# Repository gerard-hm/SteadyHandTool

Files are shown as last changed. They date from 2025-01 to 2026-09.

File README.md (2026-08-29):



# Steady Hand Tool

> “When you're racing against your own biology, the **story** is just the exhaust; the **science is the engine** and time is the fuel.”

<p align="center">
  Steady Hand Tool v1
  <br>
</p>
<p align="center">
  Steady Hand Tool v1
  <br>
</p>
<p align="center">
  Steady Hand Tool v1
  <br><br><br>
  <em>Steady Hand Tool: Mechanical stability for a wandering hand.</em>
</p>

## See it in Action
<p align="center">
  <a href="https://www.youtube.com/watch?v=Imng8o2QRBg">
    Steady Hand Tool Video
  </a>
  <br>
  <em>Demonstrating the stability and precision of the Steady Hand Tool.</em>
</p>

---

Steady Hand Tool is a manual SMD (Surface Mount Device) assembly stabilizer designed to help makers and professionals prototype PCBs with high precision. Originally created to overcome physical challenges—specifically hand tremors caused by Parkinson’s disease—this tool makes high-accuracy soldering accessible to everyone.

## 🌟 Key Features

* **Stabilized 4-DOF Movement:** Keeps your hand on a steady track while allowing full vertical and horizontal reach.
* **Near-Zero Friction:** Equipped with **14 high-quality metal bearings** and carbon fiber rods for smooth, silent, and effortless operation.
* **Modular Magnetic Coupler:** Features a quick-swap magnetic system for changing tool heads (tweezers, vacuum tips, etc.) in seconds.
* **Purely Mechanical:** No power required, no cables, and no noise. It's always ready to work when you are.
* **Heavy-Duty Base:** A weighted **680g (1.5 lb)** base ensures the arm remains stable even at full extension.
* **Open Source:** Designed to be hacked and customized. Create your own tool heads to suit your specific workflow.

## 🚀 Get Yours

<p align="center">
  <a href="https://www.crowdsupply.com/halfmarble/steady-hand-tool">
    
  </a>
</p>

<p align="center">
  <b>The Steady Hand Tool is coming to <a href="https://www.crowdsupply.com/halfmarble/steady-hand-tool">Crowd Supply</a>.</b><br>
  Sign up to be notified when the campaign launches.
</p>

---

## 🛠 Technical Specifications

* **Reach:** Approximately 250 mm (9.8 in) vertical and horizontal travel.
* **Construction:** 3D-printed components (optimized for PETG/Carbon Fiber) and 8mm carbon fiber rods.
* **Bearings:** MR128ZZ precision shielded bearings.
* **Compatibility:** Designed to support a pair of specialized reverse tweezers optimized for 0805-size components and smaller.

> [!TIP]
> **Looking to build it?** Check out our [Assembly Guide](https://github.com/gerard-hm/SteadyHandTool/blob/main/docs/assembly-guide.md) for step-by-step instructions.

## 📂 Repository Structure

```
steady-hand-tool/
├── .github/                # Issue templates and GitHub-specific config
├── hardware/               # All physical design files
│   ├── models/             # 3D models for printing
│   │   ├── stl/            # Ready-to-print files (standard)
│   │   │   ├── 3rdParty/   # Adapters for 3rd party tools
│   │   ├── step/           # High-fidelity files for CAD software
│   │   └── community/      # User-submitted tool heads
│   ├── electronics/        # (Optional) If you ever add sensors/LEDs
│   └── reference/          # Technical drawings or dimension sheets
├── docs/                   # Documentation and guides
│   ├── assembly-guide.md   # Step-by-step build instructions
│   ├── images/             # Photos and GIFs used in the guides
│   └── calibration.md      # How to tune the arm for smooth movement
├── media/                  # Marketing photos and build images
├── .gitignore              # Tells Git which files to ignore (like temp CAD files)
├── BOM.md                  # Bill of Materials (the "Shopping List")
├── CONTRIBUTING.md         # How others can help
├── LICENSE                 # CERN-OHL-S-2.0 License text
└── README.md               # The front page of your project
```

---

## ⚙️ Our Mission

"It's the only tool that I have, to help me and others manage our own **slice of PD hell.**"

The Steady Hand Tool is an engineering response to a personal biological war. It exists because "making" is a vital part of staying human. Inspired by the lived reality of Parkinson’s Disease, this tool is engineered to ensure that biological constraints never dictate the boundaries of human creativity.

## 🔧 Our Support

This is a race against time and biology. We invite you to pick up a wrench and help us optimize the hardware for the next generation of makers facing similar constraints. Feedback, CAD iterations, and mechanical refinements are the high-octane fuel that keeps this engine running.

<p align="left">
  <b>10% of the net profit</b> from selling the Steady Hand Tool will go directly to support
  <a href="https://give.michaeljfox.org/halfmarble">Team Fox</a>, the grassroots fundraising program of
  The Michael J. Fox Foundation for Parkinson’s Research.
  <br>
  <em>halfmarble is an independent Team Fox third-party fundraiser.</em>
</p>

---

## License

This project is licensed under the [**CERN-OHL-S-2.0 License**](https://choosealicense.com/licenses/cern-ohl-s-2.0/) - see the [LICENSE](LICENSE) file for details.

## Trademarks

The license above covers this repository’s hardware designs and documentation. It grants no rights to any trademark, trade name, or logo — including the Team Fox and Michael J. Fox Foundation marks, and halfmarble’s own.

---

## Credits

**Photography:** Hero images provided by [Crowd Supply](https://www.crowdsupply.com).

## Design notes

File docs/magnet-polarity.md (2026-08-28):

# Magnet Polarity Standard

Magnet orientation is the one part of this design that **cannot be recovered from a model
file**. An STL describes a ⌀4 mm hole; it says nothing about which way the magnet in that hole
faces. Two people can print the same adapter from the same file, populate it correctly by every
visible measure, and end up with parts that push each other away.

This document fixes that, so an adapter designed by one person clicks into a base owned by
another.

## The rule

> **Fixed parts present NORTH. Removable parts present SOUTH.**

| Part | Role | Exposed pole |
| :--- | :--- | :--- |
| Base tool pockets | fixed | **North** |
| Carriage tool interface | fixed | **North** |
| Tool adapters | removable | **South** |

**Every magnet in a single array shares the same pole.** There is no alternating pattern and no
keyed position. Any rotation seats correctly.

## Geometry

Each of the four base pockets holds six ⌀4 × 2 mm neodymium magnets on a **⌀18 mm bolt circle,
60° apart**. Seats are 2 mm deep, so a correctly seated magnet sits flush with the pocket floor.

```
        pocket, viewed from above          side view, one seat

              N     N                      ___________________
           N           N                   |    magnet   |     <- N face up, flush
              N     N                      |_____________|
                                           |   ⌀1.5 air relief
        all six the same pole              |
        ⌀18 bolt circle, 60 deg apart      v  ballast chamber
```

The ⌀1.5 mm hole under each seat is air relief — it lets a magnet press home instead of riding
on trapped air. It is not a through-hole to the outside.

## Installing without a compass

Neodymium magnets ship as a stack, uniformly polarised. **Do not separate the stack and sort the
magnets.** Slide one magnet off the end of the stack at a time and drop it straight into its
seat without turning it over. Every magnet then lands the same way round, and you only have to
verify the array once rather than six times.

If a magnet flips itself as it approaches the seat, it was already attracted to a neighbour in
the wrong orientation — take it out and start that seat again.

## Verifying the array

**Against known-good hardware, which is the easy case.** Offer a factory-built adapter to the
array. If it snaps flat and stays put at every rotation, the array is correct. If it pushes away
or sits proud on one side, the array is inverted.

**With a compass, for a first build.** A compass needle's marked, north-seeking end is a magnetic
*north* pole, so it is attracted to a magnet's *south* pole. Hold the compass over a seated
magnet in a base pocket:

- The marked end is **pushed away** — correct, the seat presents north.
- The marked end is **pulled in** — inverted, that array presents south.

Check one magnet per array. Because the stack method makes all six identical, one check settles
the pocket.

## If you get it wrong

A fully inverted array is harmless and reversible — the adapter simply will not stick, and the
magnets press out from the relief hole with a pin. A *single* reversed magnet among five correct
ones is the case worth avoiding: the part still holds, but it rocks on the odd magnet and the
holding force drops noticeably. That is why the whole array shares one pole. There is no phase to
get right, and a mistake is obvious rather than subtle.

## Hardware built before this standard

This document fixes the convention going forward. Prototypes assembled before it exists may be
polarised either way, because nothing recorded which way they went — that is the whole reason for
writing it down.

**Build production hardware to the standard above, not to a prototype.** If an old base and a new
adapter push apart, the old base predates the convention; it is not evidence that the convention
is wrong.

Re-polarising an existing part is straightforward and reversible. Push each magnet out through
its ⌀1.5 mm air-relief hole with a pin, turn it over, and press it back in. There is no adhesive
and nothing to damage.

## For adapter designers

Build to **south exposed** and your adapter will seat in any base built to this standard, at any
rotation. Copy the seat pattern from `InterfaceTemplate.stl` rather than re-deriving it — the
⌀18 bolt circle and 2 mm seat depth are what make the parts interchangeable, and the polarity
rule above is what makes them interchangeable *between owners*.

## Why not alternating poles

Alternating north and south around the ring would hold harder, because flux closes between
neighbours, and it would key the adapter to three rotational positions. It was rejected: a
mis-phased adapter would actively *repel* its base, which is a poor failure mode for someone
seating a tool one-handed with a tremor. Uniform polarity trades some holding force for an
interface that cannot be assembled out of phase.

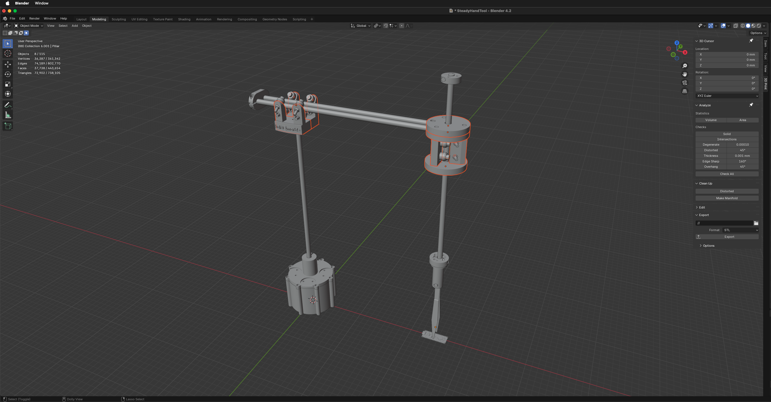
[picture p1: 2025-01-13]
SteadyHandToolModel.png

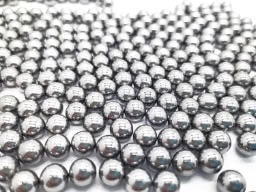
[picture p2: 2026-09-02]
media/weights.jpg

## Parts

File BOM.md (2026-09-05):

# Steady Hand Tool

**A stabilizing pick-and-place arm for precision SMD assembly.**




<p align="center">
  Steady Hand Tool v1
  <br>
  <em>Steady Hand Tool — when you need help holding down really tiny parts.</em>
</p>

---

## 🛒 Bill of Materials (BOM)

The Steady Hand Tool is designed for easy sourcing. You can find the links and visual references for each component below (please notice that these are affiliate links).

### 🏗️ Structural Hardware

| Image | Item | Specification | Purpose |
| :---: | :--- | :--- | :--- |
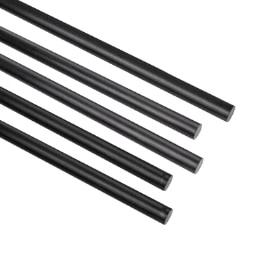
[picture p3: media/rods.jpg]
|  | [**Carbon Fiber Rods**](https://amzn.to/4jpyyZC) | 8mm Diameter x 300mm (**4 required**) | 2 horizontal rails, 1 vertical mast, 1 vertical tool rod |
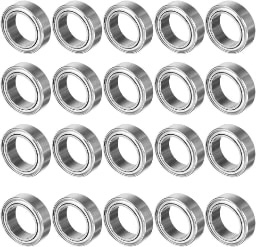
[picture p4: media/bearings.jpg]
|  | [**MR128ZZ Bearings**](https://amzn.to/42kMWMD) | 8x12x3.5mm (14 required) | Frictionless carriage movement |
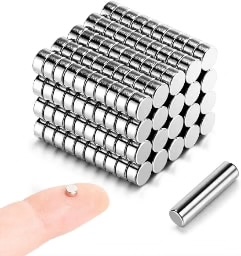
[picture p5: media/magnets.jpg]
|  | [**Magnets**](https://amzn.to/4hq1puZ) | 4mm x 2mm Neodymium (56 required, buy 60) | Magnetic tool coupler interface. **Orientation matters** — see the [Magnet Polarity Standard](docs/magnet-polarity.md) |
| | **Base Ballast** | Round steel shot, **1.5 - 2.0 mm** (nominal 2.0 mm). Approx. **517 g** per base | Fills the printed base to **680 g ± 10 g**. The machined aluminium base needs none. **Size is not a preference** — read the note below before you buy any |

**Magnet count, broken down:** 24 in the base (four tool pockets, six each), 24 in the four
tool adapters, and 8 in the tool interface — 56 in total. Buy 60; they are small, and one
will find the floor.

**On the ballast, before you buy any.** The shot goes into the printed base through a **⌀8 mm
socket**, and that socket — not the chamber — is what governs. Granular flow arches when the
opening falls below roughly four particle diameters, so anything much over 2 mm bridges at the
mouth and leaves the outer chamber empty. At the other end, the chamber vents are ⌀1.5 mm and
finer shot runs straight back out. **So: 1.5 - 2.0 mm, nominal 2.0.** SAE **S-780** blasting shot
and **#9 steel reloading shot** both sit in that window.

**This entry used to link to 6.35 mm slingshot ammo, and it does not work.** A base filled with it
reaches about **619 g against the 680 g spec** — it bridges at the socket and packs to 49% where
a settled fill reaches 60%. The link has been removed rather than swapped, because the search
terms above are what you actually want. Fill by weighing the base, not by measuring the shot, and
tap or vibrate it between pours. Full method: [Step 1 of the assembly
guide](docs/assembly-guide.md#step-1-weight-the-base).

### 🔩 Fasteners

| Image | Item | Specification | Purpose |
| :---: | :--- | :--- | :--- |
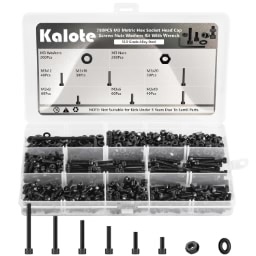
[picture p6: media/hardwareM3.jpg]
|  | [**M3 Hardware**](https://amzn.to/42phRHt) | Stainless steel. **6x M3x16, 3x M3x20, 2x M3x10, 2x M3x8, and 7 nuts** | Structural assembly of the arm |
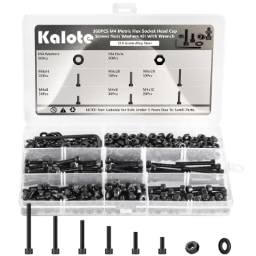
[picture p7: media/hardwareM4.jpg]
|  | [**M4 Hardware**](https://amzn.to/3WslSXP) | Stainless steel. **18x M4x16, 1x M4x10, and 19 nuts** | Structural assembly of the arm |

Buy a few spares of each size. **Neither base takes a fastener of any kind** — every one of these
goes into the arm. The step-by-step breakdown is in the
[assembly guide](docs/assembly-guide.md#-preparation-fasteners-sorting).

### 🔧 Tools

| Image | Item | Specification | Purpose |
| :---: | :--- | :--- | :--- |
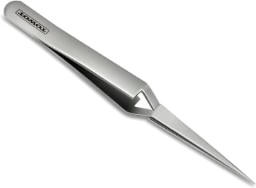
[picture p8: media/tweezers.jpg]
|  | [**Reverse Tweezers**](https://www.amazon.com/dp/B07V8SLF2T?tag=halfmarble0f-20) | Reverse action (self-closing) — squeeze to open | Holding SMD parts during placement |
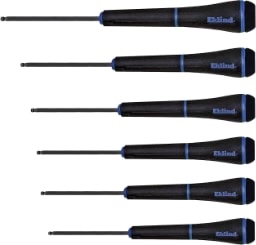
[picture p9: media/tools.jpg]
|  | [**Ball-Hex Drivers**](https://amzn.to/4jlawie) | Metric Allen Key Set | Recommended for assembly |

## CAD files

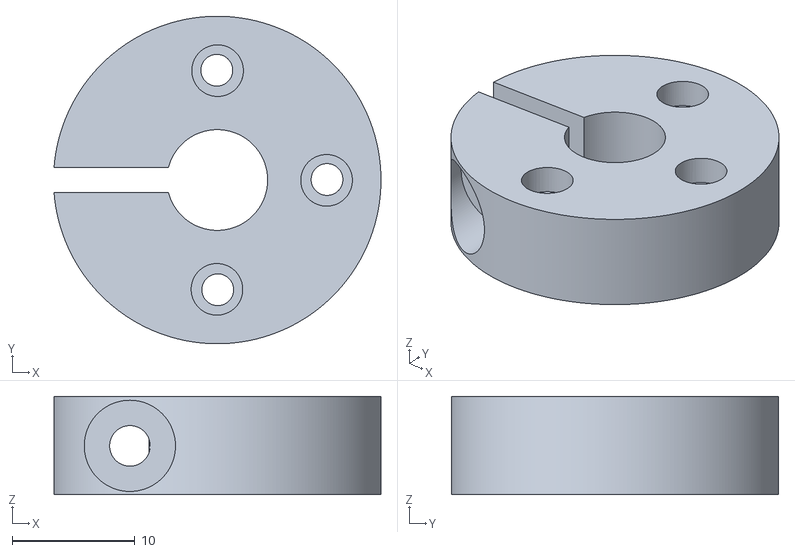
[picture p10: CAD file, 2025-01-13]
SteadyHandTool-Stopper.stl
26.6 x 26.7 x 8.00

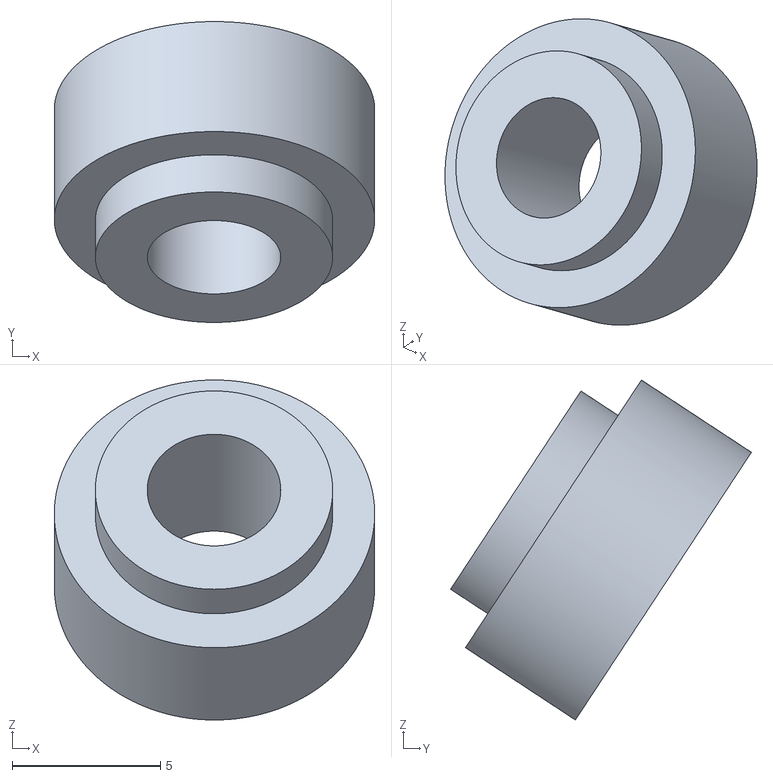
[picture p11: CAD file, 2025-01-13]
SteadyHandTool-Spacer.stl
10.8 x 10.1 x 11.5

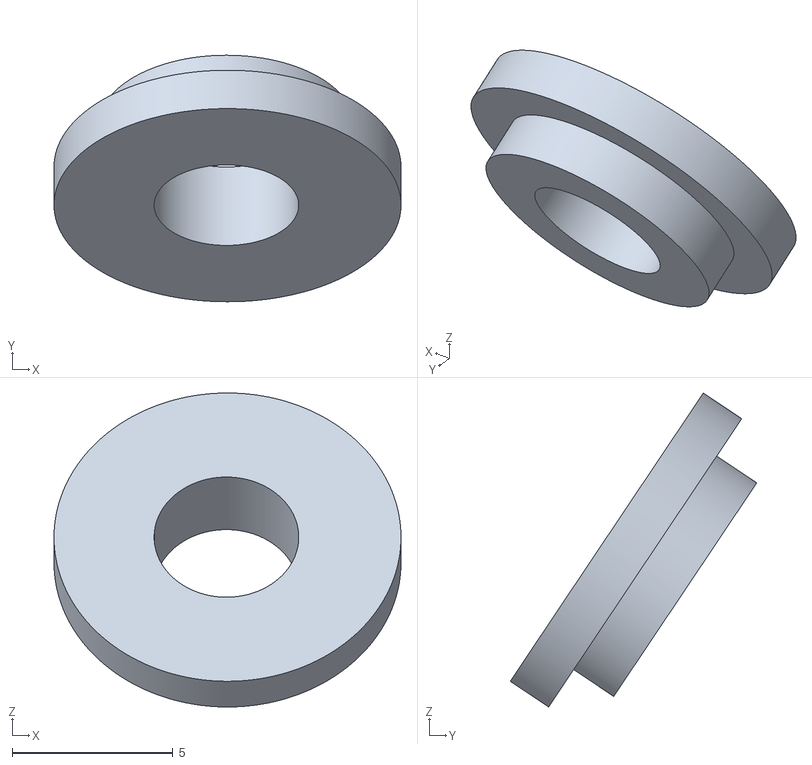
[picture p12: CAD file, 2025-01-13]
SteadyHandTool-SpacerSmall.stl
10.8 x 7.67 x 9.77

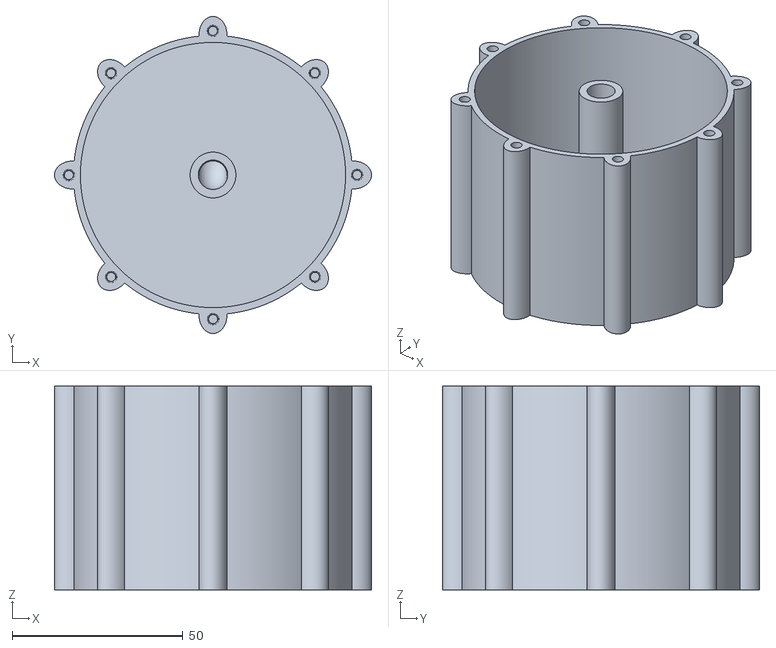
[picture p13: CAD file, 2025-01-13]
SteadyHandTool-BaseBottom.stl
92.7 x 92.7 x 59.5

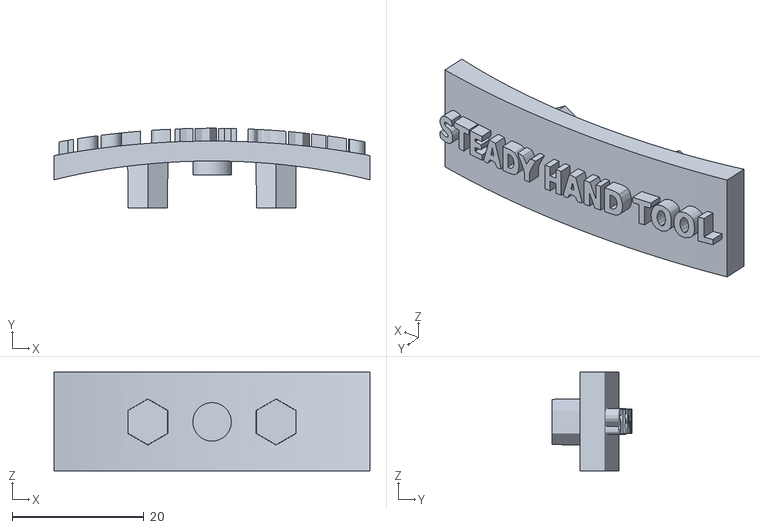
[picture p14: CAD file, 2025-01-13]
SteadyHandTool-Plate_STEADY_HAND_TOOL.stl
48.0 x 12.1 x 15.0

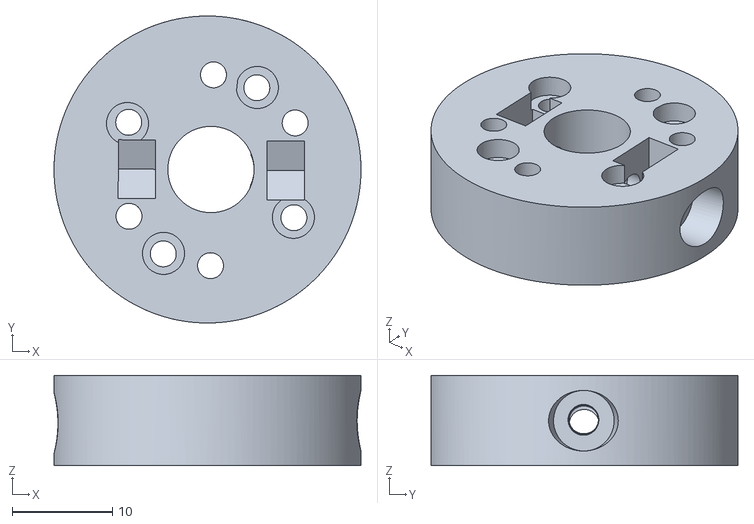
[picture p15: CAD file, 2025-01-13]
SteadyHandTool-InterfaceRing.stl
30.7 x 30.7 x 8.99

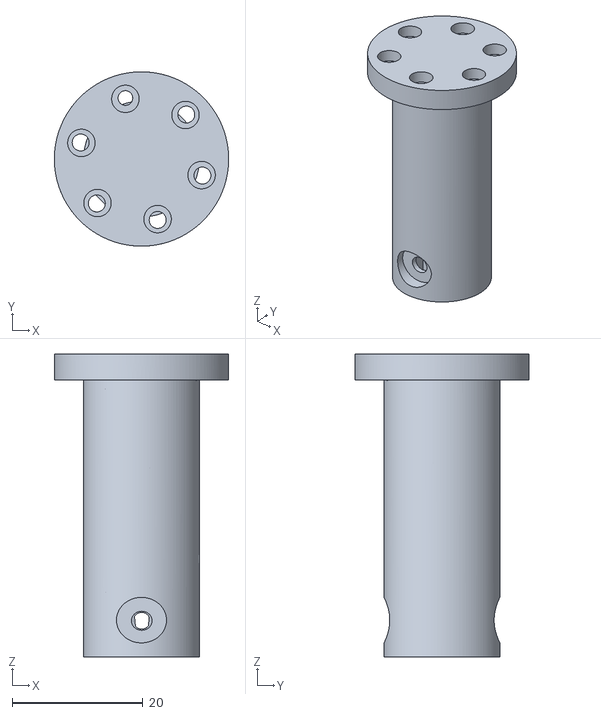
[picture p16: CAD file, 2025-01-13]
SteadyHandTool-Interface.stl
26.7 x 26.7 x 46.3

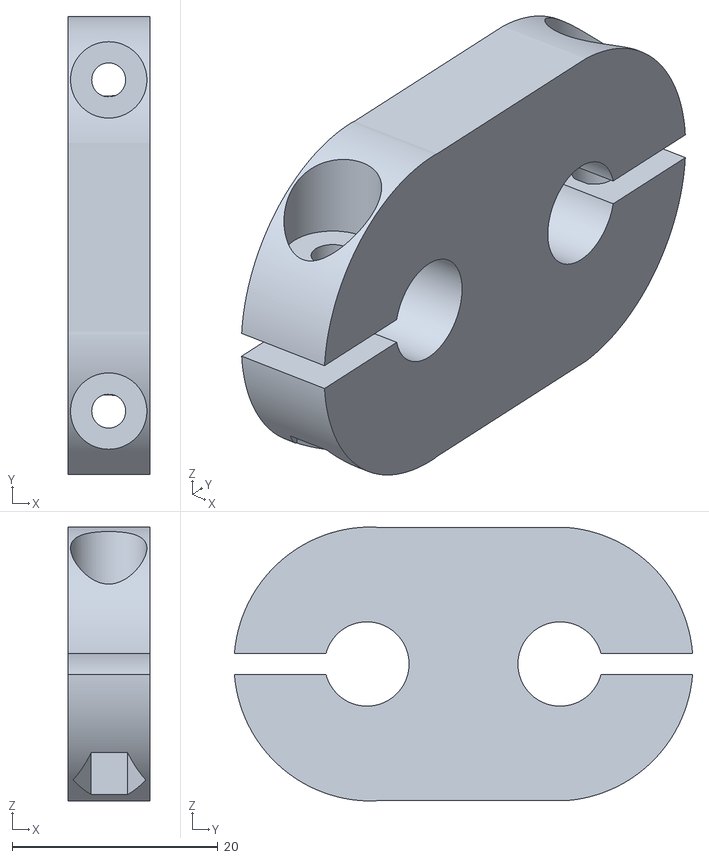
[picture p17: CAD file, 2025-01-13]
SteadyHandTool-Aligner.stl
8.00 x 44.6 x 26.7

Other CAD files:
SteadyHandTool-Plate_half LOGO marble.stl

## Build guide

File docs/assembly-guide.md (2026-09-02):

# Steady Hand Tool Assembly Guide - Part 1

This assembly guide is based on the [Steady Hand Tool DIY Part 1](https://www.youtube.com/watch?v=_OBHK19EvW4) video tutorial.

**Estimated Time:** 30 Minutes

---

## 🛠️ Required Tools
* **2.5mm** Hexball screwdriver
* **3.0mm** Hexball screwdriver

---

## 🔩 Preparation: Fasteners Sorting
Before starting, sort your bolts into two main piles based on their diameter and length:
* **M3 Bolts** (Thinner)
* **M4 Bolts** (Thicker)

These are the totals the steps below actually consume. Count them out before you start — it is
much easier than discovering a shortfall at Step 12.

| Fastener | Quantity | Where it goes |
| :--- | ---: | :--- |
| M3 x 8 | 2 | Step 12 |
| M3 x 10 | 2 | Step 11 |
| M3 x 16 | 6 | Steps 8, 9, 10 |
| M3 x 20 | 3 | Step 8 |
| M3 nuts | 7 | Steps 9, 10, 11, 12 |
| M4 x 10 | 1 | Step 8 |
| M4 x 16 | 18 | Steps 4, 6 |
| M4 nuts | 19 | Steps 4, 6, 8 |

Buy a couple of spares of each. They are small, they cost cents, and one will find the floor.

---

## 🧩 Assembly Steps

### Step 1: Weight the Base
*Printed base only. The machined aluminium base is solid and reaches its mass as material — skip to Step 2.*

* **Media: round steel shot, 1.5 - 2.0 mm, nominal 2.0 mm.** This is not a preference, and it is
  bounded at both ends:
  * **Nothing above 2.0 mm.** The shot enters through the central **⌀8 mm socket**, and that
    socket, not anything inside the chamber, is the restriction that governs. Granular flow
    arches when the opening drops below roughly four particle diameters. At 2.0 mm the socket is
    four ball diameters wide and the shot flows; at 6.35 mm it is barely over one, the shot goes
    in single file, and it bridges at the mouth leaving the outer chamber empty.
  * **Nothing below 1.5 mm.** The chamber vents are ⌀1.5 mm. Anything finer runs back out of them.
  * SAE **S-780** blasting shot and **#9 steel reloading shot** both sit in this window. If a
    grade publishes a screen analysis, check its tail stays above 1.5 mm.
* **Fill through the ⌀8 socket in the top of the base.** There is no cover and no fasteners — the
  socket is the fill port, and the base is finished as soon as it is at weight. A funnel helps.
* **Pour in stages, tapping or vibrating the base between them.** A settled fill reaches the
  target comfortably; one unsettled pour lands at the bottom of the tolerance or below.
* **Weigh the base. Do not measure out the shot.** The specification is **680 g ± 10 g for the
  finished base**, and roughly **517 g** of shot gets there — but printed shell mass varies with
  printer, material and infill, so the scale is the authority and 517 g is only indicative.

**Learn from our mistake instead of repeating it.** Our own first fill used 6.35 mm slingshot
ammo. It bridged at the socket, packed to 49% where a settled fill reaches 60%, and produced a
**619 g base against a 680 g spec**. The chamber was never too small. The media was too big.

### Step 2: Sorting Bolts
* Differentiate between M3 and M4 bolts to avoid mistakes in later steps.

### Step 3: Close the Base — *no longer required, skip it*
* The video secures a base cover with **5x M4x16 bolts and 1x M4 nut**. **Neither base has a
  cover any more.**
* The printed base is filled through the ⌀8 socket in Step 1 and is finished once it is at
  weight; the machined base is solid aluminium. **Neither takes a fastener of any kind.**
* The step number is kept so the guide still lines up with the video. Keep those six fasteners
  as spares.

### Step 4: Prepare the Bearings
* **Parts:** 14x M4x16 bolts and 14x M4 nuts.
* **Assembly Order:** Thin spacer ➡️ Metal bearing ➡️ Fat spacer.
* Repeat this for all 14 bearing sets.

### Step 5: Horizontal Cage (Part A)
* **Parts:** 8 prepared bearing sets.
* Insert the bearing sets into the horizontal cage housing.

### Step 6: Horizontal Cage (Part B)
* **Parts:** 4x M4x16 bolts and 4x M4 nuts.
* Secure the cage assembly.
* **Pro Tip:** In tight spots, thread a long bolt in from the far side as a temporary handle to
  guide a nut into its pocket and hold it there while you start the real fastener. The M3x20
  bolts are not needed until Step 8, so one of those is a good size for the job.

### Step 7: Vertical Cage (Part A)
* **Parts:** 6 prepared bearing sets.
* Assemble the bearing sets into the vertical cage components.

### Step 8: Vertical Cage (Part B)
* **Parts:** 3x M3x16 bolts, 3x M3x20 bolts, 1x M4x10 bolt, 1x M4 nut.
* Join the vertical cage components and attach the vertical rods.
* **Note:** Use the single short **M4x10mm** bolt specifically for the rod interface.

### Step 9: Horizontal Stop
* **Parts:** 2x M3x16 bolts and 2x M3 nuts.
* Assemble and slide the stop onto the horizontal rods.

### Step 10: Vertical Stop
* **Parts:** 1x M3x16 bolt and 1x M3 nut.
* Install the stop onto the vertical rod to limit the tool's travel.

### Step 11: Interface Ring
* **Parts:** 2x M3x10 bolts and 2x M3 nuts.
* Secure the ring that interfaces with the tool head.

### Step 12: Tool Interface
* **Parts:** 2x M3x8 bolts and 2x M3 nuts.
* Install the final interface component that will hold your specific tool.

### Step 13: Branding
* Install the **Steady Hand Tool** and **halfmarble** logo plates into their designated slots.

---

**Next Step:** Watch Part 2 to learn how to install the magnets for the base and interface.

> **Before you install any magnet, read the [Magnet Polarity Standard](magnet-polarity.md).**
> Orientation cannot be read from a model file, and getting it wrong is what stops one
> person's tool adapter from seating in another person's base.

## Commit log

2025-01-13 add 3d models
    [SteadyHandTool-Aligner.stl, SteadyHandTool-BaseBottom.stl, SteadyHandTool-Interface.stl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]
2026-08-25 Add magnet polarity standard
    Magnet orientation cannot be recovered from an STL, so adapters built by
    different people could repel each other. Fixes the convention: fixed parts
    present north, removable parts present south, uniform within each array.
2026-08-25 Add magnet quantity to the BOM
    The BOM specified 4x2 mm neodymium but never said how many. 56 required:
    24 base, 24 adapters, 8 interface. Links the polarity standard, since
    orientation is not recoverable from the model files.
2026-08-28 Update the assembly guide link after the repository rename
2026-08-28 Note that pre-standard prototypes may differ
    The convention governs new builds. An old base that repels a new adapter
    predates the standard rather than contradicting it, and re-polarising is a
    pin-push through the relief hole.
2026-09-02 Correct the ballast specification and fastener counts
    The BOM asked for "Metal BBs or Bearing Balls" with no size at all, and the
    link behind it sold 6.35 mm slingshot ammo. That media bridges at the base's
    8 mm fill socket and packs to only 49 percent, producing a 619 g base against
    the published 680 g spec. Both documents now give the 1.5-2.0 mm window and
    why it is bounded at each end: the socket governs the ceiling, since granular
    flow arches below roughly four particle diameters, and the 1.5 mm chamber
    vents set the floor. The fill is controlled by weighing the finished base to
    680 g +/- 10 g, not by measuring out the shot, because printed shell mass
    varies with printer, material and in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
2026-09-02 Re-encode the component images as JPEG
    Nine of the twelve files in media/ were JPEG XL or AVIF despite carrying a
    .jpg extension, and they are served as image/jpeg. Chrome has no JPEG XL
    support, so the bearings, magnets and weights thumbnails did not render for
    most visitors to the BOM. All nine are now baseline JPEG. The three hero
    shots were already correct and are untouched.
2026-09-05 Update BOM tweezer specification and link

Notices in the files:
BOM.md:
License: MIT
